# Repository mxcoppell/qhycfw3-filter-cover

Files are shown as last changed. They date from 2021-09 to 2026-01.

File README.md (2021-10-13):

# QHYCFW3 Filter Mask 3D Models

QHYCFW3S-US 7x31mm with Separators and Sunkened Screw Caps

All, the OpenSCAD script is designed/implemented for generating 3D printable models for QHYCFW3 filter wheel filter masks to make installing unmounted filters much easier. User could change the following parameter (please check with official QHYCCD CFW3 filter wheel drawings: https://www.qhyccd.com/qhycfw3/). The filter covers make filter installation to QHYCFW3 very easy - It helps to center the filters, avoid light leaks and secures the installation. It's a much better solution than the factory M.2 screws + M.2 washers. 

Please note, this design is for unmounted filters with thickness of 3mm. - For example, Chroma/Astrodon unmounted 31mm filters, unmounted 50mm round filters and Antlia unmounted 50mm round filters. If the filter thickness is 2mm or below, this solution is not feasible.

I printed mine at a local library, the cost is 30 cents in this highly-inflated world.

# Supported CFW3 Models

Currently, the following CFW3 filter wheels are supported. The square filter version is not available in current version.

- _QHYCFW3-S-SR 7x31mm_
- _QHYCFW3-S-SR 6x36mm_
- _QHYCFW3-S-US 7x31mm_
- _QHYCFW3-S-US 6x36mm_
- _QHYCFW3-M-SR 8x31mm_
- _QHYCFW3-M-SR 7x36mm_
- _QHYCFW3-M-SR 5x50mm_
- _QHYCFW3-M-US 8x31mm_
- _QHYCFW3-M-US 7x36mm_
- _QHYCFW3-M-US 5x50mm_
- _QHYCFW3-L    7x50mm_
- _QHYCFW3-XL   9x50mm_

# Filter Cover Styles

There are 4 styles with combinations of separators and sunkened screw caps. With separator, the user could easily snap the printout into individual filter covers. The sunkened screw caps requires better 3D printers. The printer I use from the local library can't really handle it well. So I just use the version without sunkened screw caps. 

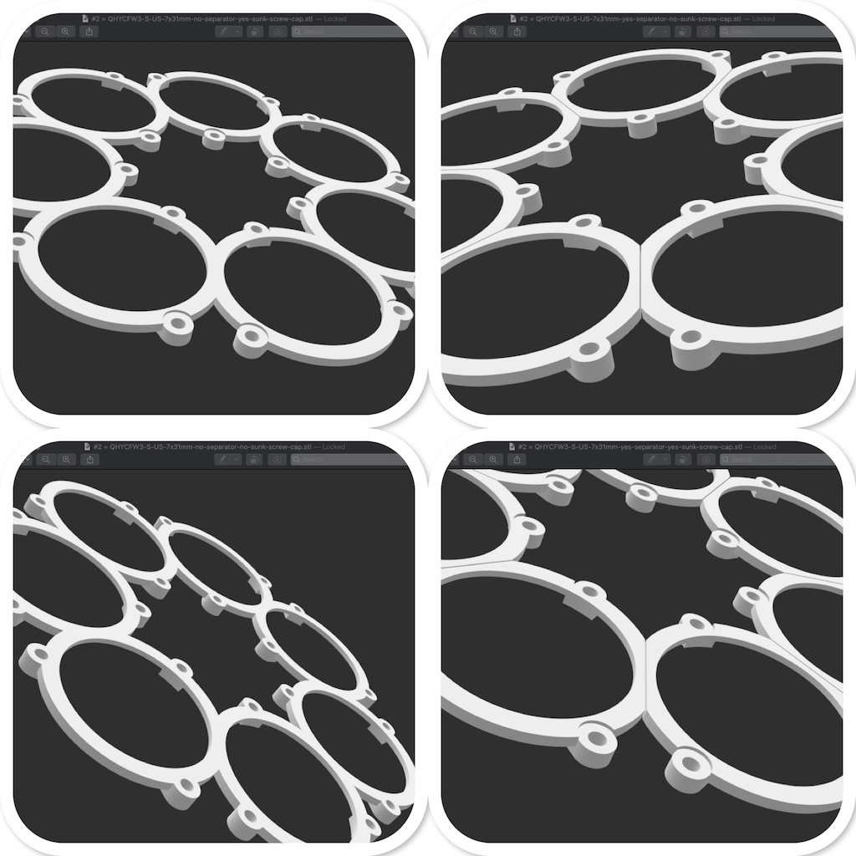
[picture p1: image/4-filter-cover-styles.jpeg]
4 Mask Cover Styles


# Pre-rendered STL Download

Pre-rendered STL files could be downloaded from the following table:
```
  S - Separators
SSC - Sunkened Screw Caps
```

| Filter Model  | No S / No SSC | No S / Yes SSC | Yes S / No SSC | Yes S / Yes SSC |
| --- | --- | --- | --- | --- |
| QHYCFW3-S-SR 7x31mm  | [download](https://github.com/mxcoppell/qhycfw3-filter-cover/blob/main/stl/%230%20%3D%20QHYCFW3-S-SR-7x31mm-no-separator-no-sunk-screw-cap.stl)  | [download](https://github.com/mxcoppell/qhycfw3-filter-cover/blob/main/stl/%230%20%3D%20QHYCFW3-S-SR-7x31mm-no-separator-yes-sunk-screw-cap.stl)  | [download](https://github.com/mxcoppell/qhycfw3-filter-cover/blob/main/stl/%230%20%3D%20QHYCFW3-S-SR-7x31mm-yes-separator-no-sunk-screw-cap.stl)  | [download](https://github.com/mxcoppell/qhycfw3-filter-cover/blob/main/stl/%230%20%3D%20QHYCFW3-S-SR-7x31mm-yes-separator-yes-sunk-screw-cap.stl)  |
| QHYCFW3-S-SR 6x36mm  | [download](https://github.com/mxcoppell/qhycfw3-filter-cover/blob/main/stl/%231%20-%20QHYCFW3-S-SR-6x36mm-no-separator-no-sunk-screw-cap.stl)  | [download](https://github.com/mxcoppell/qhycfw3-filter-cover/blob/main/stl/%231%20-%20QHYCFW3-S-SR-6x36mm-no-separator-yes-sunk-screw-cap.stl)  | [download](https://github.com/mxcoppell/qhycfw3-filter-cover/blob/main/stl/%231%20-%20QHYCFW3-S-SR-6x36mm-yes-separator-no-sunk-screw-cap.stl)  | [download](https://github.com/mxcoppell/qhycfw3-filter-cover/blob/main/stl/%231%20-%20QHYCFW3-S-SR-6x36mm-yes-separator-yes-sunk-screw-cap.stl)  |
| QHYCFW3-S-US 7x31mm  | [download](https://github.com/mxcoppell/qhycfw3-filter-cover/blob/main/stl/%232%20%3D%20QHYCFW3-S-US-7x31mm-no-separator-no-sunk-screw-cap.stl)  | [download](https://github.com/mxcoppell/qhycfw3-filter-cover/blob/main/stl/%232%20%3D%20QHYCFW3-S-US-7x31mm-no-separator-yes-sunk-screw-cap.stl)  | [download](https://github.com/mxcoppell/qhycfw3-filter-cover/blob/main/stl/%232%20%3D%20QHYCFW3-S-US-7x31mm-yes-separator-no-sunk-screw-cap.stl)  | [download](https://github.com/mxcoppell/qhycfw3-filter-cover/blob/main/stl/%232%20%3D%20QHYCFW3-S-US-7x31mm-yes-separator-yes-sunk-screw-cap.stl)  |
| QHYCFW3-S-US 6x36mm  | [download](https://github.com/mxcoppell/qhycfw3-filter-cover/blob/main/stl/%233%20-%20QHYCFW3-S-US-6x36mm-no-separator-no-sunk-screw-cap.stl)  | [download](https://github.com/mxcoppell/qhycfw3-filter-cover/blob/main/stl/%233%20-%20QHYCFW3-S-US-6x36mm-no-separator-yes-sunk-screw-cap.stl)  | [download](https://github.com/mxcoppell/qhycfw3-filter-cover/blob/main/stl/%233%20-%20QHYCFW3-S-US-6x36mm-yes-separator-no-sunk-screw-cap.stl)  | [download](https://github.com/mxcoppell/qhycfw3-filter-cover/blob/main/stl/%233%20-%20QHYCFW3-S-US-6x36mm-yes-separator-yes-sunk-screw-cap.stl)  |
| QHYCFW3-M-SR 8x31mm  | [download](https://github.com/mxcoppell/qhycfw3-filter-cover/blob/main/stl/%234%20-%20QHYCFW3-M-SR-8x31mm-no-separator-no-sunk-screw-cap.stl)  | [download](https://github.com/mxcoppell/qhycfw3-filter-cover/blob/main/stl/%234%20-%20QHYCFW3-M-SR-8x31mm-no-separator-yes-sunk-screw-cap.stl)  | [download](https://github.com/mxcoppell/qhycfw3-filter-cover/blob/main/stl/%234%20-%20QHYCFW3-M-SR-8x31mm-yes-separator-no-sunk-screw-cap.stl)  | [download](https://github.com/mxcoppell/qhycfw3-filter-cover/blob/main/stl/%234%20-%20QHYCFW3-M-SR-8x31mm-yes-separator-yes-sunk-screw-cap.stl)  |
| QHYCFW3-M-SR 7x36mm  | [download](https://github.com/mxcoppell/qhycfw3-filter-cover/blob/main/stl/%235%20-%20QHYCFW3-M-SR-7x36mm-no-separator-no-sunk-screw-cap.stl)  | [download](https://github.com/mxcoppell/qhycfw3-filter-cover/blob/main/stl/%235%20-%20QHYCFW3-M-SR-7x36mm-no-separator-yes-sunk-screw-cap.stl)  | [download](https://github.com/mxcoppell/qhycfw3-filter-cover/blob/main/stl/%235%20-%20QHYCFW3-M-SR-7x36mm-yes-separator-no-sunk-screw-cap.stl)  | [download](https://github.com/mxcoppell/qhycfw3-filter-cover/blob/main/stl/%235%20-%20QHYCFW3-M-SR-7x36mm-yes-separator-yes-sunk-screw-cap.stl)  |
| QHYCFW3-M-SR 5x50mm  | [download](https://github.com/mxcoppell/qhycfw3-filter-cover/blob/main/stl/%236%20-%20QHYCFW3-M-SR-5x50mm-no-separator-no-sunk-screw-cap.stl)  | [download](https://github.com/mxcoppell/qhycfw3-filter-cover/blob/main/stl/%236%20-%20QHYCFW3-M-SR-5x50mm-no-separator-yes-sunk-screw-cap.stl)  | [download](https://github.com/mxcoppell/qhycfw3-filter-cover/blob/main/stl/%236%20-%20QHYCFW3-M-SR-5x50mm-yes-separator-no-sunk-screw-cap.stl)  | [download](https://github.com/mxcoppell/qhycfw3-filter-cover/blob/main/stl/%236%20-%20QHYCFW3-M-SR-5x50mm-yes-separator-yes-sunk-screw-cap.stl)  |
| QHYCFW3-M-US 8x31mm  | [download](https://github.com/mxcoppell/qhycfw3-filter-cover/blob/main/stl/%237%20-%20QHYCFW3-M-US-8x31mm-no-separator-no-sunk-screw-cap.stl)  | [download](https://github.com/mxcoppell/qhycfw3-filter-cover/blob/main/stl/%237%20-%20QHYCFW3-M-US-8x31mm-no-separator-yes-sunk-screw-cap.stl)  | [download](https://github.com/mxcoppell/qhycfw3-filter-cover/blob/main/stl/%237%20-%20QHYCFW3-M-US-8x31mm-yes-separator-no-sunk-screw-cap.stl)  | [download](https://github.com/mxcoppell/qhycfw3-filter-cover/blob/main/stl/%237%20-%20QHYCFW3-M-US-8x31mm-yes-separator-yes-sunk-screw-cap.stl)  |
| QHYCFW3-M-US 7x36mm  | [download](https://github.com/mxcoppell/qhycfw3-filter-cover/blob/main/stl/%238%20-%20QHYCFW3-M-US-7x36mm-no-separator-no-sunk-screw-cap.stl)  | [download](https://github.com/mxcoppell/qhycfw3-filter-cover/blob/main/stl/%238%20-%20QHYCFW3-M-US-7x36mm-no-separator-yes-sunk-screw-cap.stl)  | [download](https://github.com/mxcoppell/qhycfw3-filter-cover/blob/main/stl/%238%20-%20QHYCFW3-M-US-7x36mm-yes-separator-no-sunk-screw-cap.stl)  | [download](https://github.com/mxcoppell/qhycfw3-filter-cover/blob/main/stl/%238%20-%20QHYCFW3-M-US-7x36mm-yes-separator-yes-sunk-screw-cap.stl)  |
| QHYCFW3-M-US 5x50mm  | [download](https://github.com/mxcoppell/qhycfw3-filter-cover/blob/main/stl/%239%20-%20QHYCFW3-M-US-5x50mm-no-separator-no-sunk-screw-cap.stl)  | [download](https://github.com/mxcoppell/qhycfw3-filter-cover/blob/main/stl/%239%20-%20QHYCFW3-M-US-5x50mm-no-separator-yes-sunk-screw-cap.stl)  | [download](https://github.com/mxcoppell/qhycfw3-filter-cover/blob/main/stl/%239%20-%20QHYCFW3-M-US-5x50mm-yes-separator-no-sunk-screw-cap.stl)  | [download](https://github.com/mxcoppell/qhycfw3-filter-cover/blob/main/stl/%239%20-%20QHYCFW3-M-US-5x50mm-yes-separator-yes-sunk-screw-cap.stl)  |
| QHYCFW3-L 7x50mm  | [download](https://github.com/mxcoppell/qhycfw3-filter-cover/blob/main/stl/%2310%20-%20QHYCFW3-L-7x50mm-no-separator-no-sunk-screw-cap.stl)  | [download](https://github.com/mxcoppell/qhycfw3-filter-cover/blob/main/stl/%2310%20-%20QHYCFW3-L-7x50mm-no-separator-yes-sunk-screw-cap.stl)  | [download](https://github.com/mxcoppell/qhycfw3-filter-cover/blob/main/stl/%2310%20-%20QHYCFW3-L-7x50mm-yes-separator-no-sunk-screw-cap.stl)  | [download](https://github.com/mxcoppell/qhycfw3-filter-cover/blob/main/stl/%2310%20-%20QHYCFW3-L-7x50mm-yes-separator-yes-sunk-screw-cap.stl)  |
| QHYCFW3-XL 9x50mm  | [download](https://github.com/mxcoppell/qhycfw3-filter-cover/blob/main/stl/%2311%20-%20QHYCFW3-XL-9x50mm-no-separator-no-sunk-screw-cap.stl)  | [download](https://github.com/mxcoppell/qhycfw3-filter-cover/blob/main/stl/%2311%20-%20QHYCFW3-XL-9x50mm-no-separator-yes-sunk-screw-cap.stl)  | [download](https://github.com/mxcoppell/qhycfw3-filter-cover/blob/main/stl/%2311%20-%20QHYCFW3-XL-9x50mm-yes-separator-no-sunk-screw-cap.stl)  | [download](https://github.com/mxcoppell/qhycfw3-filter-cover/blob/main/stl/%2311%20-%20QHYCFW3-XL-9x50mm-yes-separator-yes-sunk-screw-cap.stl)  |

# Customization

You could also download the OpenSCAD code ([qhycfw3-filter-cover.scad](https://github.com/mxcoppell/qhycfw3-filter-cover/blob/main/openscad/qhycfw3-filter-cover.scad))to do your own customization. 

The following parameters could be adjusted. (Of course you could change other part of the code to do bug fixes or design modifications.)

```
//
//  User customizable data
//
cfw_model                   = 2;        //  !!! Please set your CFW model here !!!
                                        //
                                        //   0 - QHYCFW3-S-SR 7x31mm
                                        //   1 - QHYCFW3-S-SR 6x36mm
                                        //   2 - QHYCFW3-S-US 7x31mm
                                        //   3 - QHYCFW3-S-US 6x36mm
                                        //   4 - QHYCFW3-M-SR 8x31mm
                                        //   5 - QHYCFW3-M-SR 7x36mm
                                        //   6 - QHYCFW3-M-SR 5x50mm
                                        //   7 - QHYCFW3-M-US 8x31mm
                                        //   8 - QHYCFW3-M-US 7x36mm
                                        //   9 - QHYCFW3-M-US 5x50mm
                                        //  10 - QHYCFW3-L    7x50mm
                                        //  11 - QHYCFW3-XL   9x50mm

use_filter_slot_separators  = false;    //  Pre-cut into individual filter covers
                                        //      true - cut | false - don't cut

use_screw_cap_sinks         = false;    //  Use sinks for screw caps, 
                                        //      true - use | false - don't use
                                        
cover_slot_shrink_diameter  = 0.45;     //  Diameter shink size for cover slot from QHY slot diameter
```

# Printing

It is suggested to use nozzle size <= 0.4, layer 0.1mm when printing the models. When printing, please make sure the following side is facing up (against the the printer bed). I am pretty confident any regular 3D printer could handle this job. Either ABS or PETG should be fine along with other fancier filaments. As far as it's flexible and harmless to your precious filter glasses. 

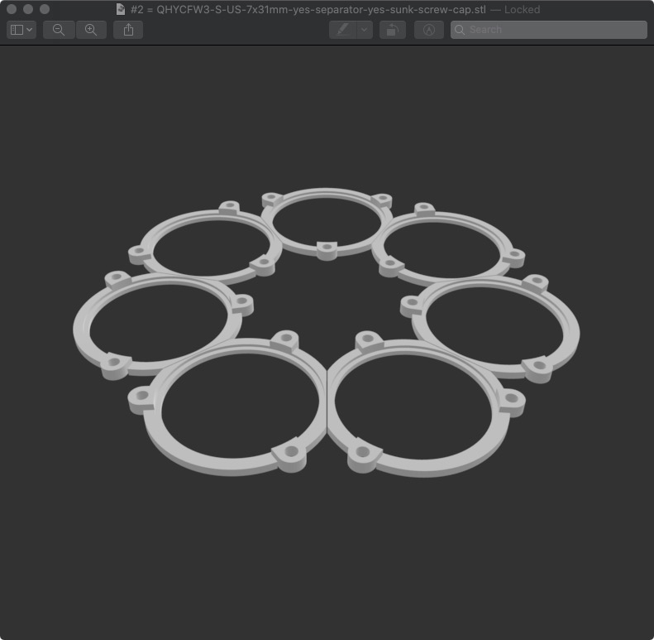
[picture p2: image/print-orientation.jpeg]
Side to face up during printing


# License

GPL - https://www.gnu.org/licenses/gpl-3.0.en.html

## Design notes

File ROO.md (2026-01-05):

# QHYCFW3 Filter Mask Project

> [!IMPORTANT]
> **Agent Instructions:** All agents MUST read this [`ROO.md`](ROO.md) file first before starting any work on the project.

This project provides an OpenSCAD script and pre-rendered STL files for creating 3D-printable filter masks for **QHYCFW3 filter wheels**.

## 1. Purpose and Target Hardware

The goal of this project is to simplify the installation of unmounted filters, improve centering, prevent light leaks, and secure filters more effectively than factory M.2 screws and washers.

- **Target Hardware:** Supports QHYCFW3 models S-SR, S-US, M-SR, M-US, L, and XL (round filters only; square filters are not supported).
- **Filter Compatibility:** Optimized for unmounted filters with a **3mm thickness** (e.g., Chroma, Astrodon, Antlia). It is not suitable for filters 2mm thick or thinner.

## 2. OpenSCAD Model Structure

The model is parametric and organized into functional modules within [`openscad/qhycfw3-filter-cover.scad`](openscad/qhycfw3-filter-cover.scad).

### Key Parameters

- `cfw_model`: Selects the specific CFW model (0–11) from a predefined dataset.
- `use_filter_slot_separators`: Boolean to include thin cuts for snapping the print into individual covers.
- `use_screw_cap_sinks`: Boolean to enable recessed screw head slots (requires high-precision printing).
- `cover_slot_shrink_diameter`: Adjusts the fit tolerance (default `0.45mm`).

### Core Modules

- `single_filter_slot()`: The primary building block, combining the filter base, screw extensions, and holes.
- `three_screw_*`: Helper modules that distribute screw features (extensions, holes, sinks) in a 120-degree pattern.
- `filter_separators()`: Generates radial cutouts to separate the masks.
- `filter_slots()` / `copy_filter_slot()`: Handles the circular arrangement of multiple masks based on the selected CFW model's geometry.

## 3. Development and Contribution Guidelines

- **Customization:** Users are encouraged to modify the OpenSCAD script for bug fixes or design improvements.
- **Printing Recommendations:**
  - **Nozzle size:** <= 0.4mm.
  - **Layer height:** 0.1mm.
  - **Material:** ABS or PETG (must be flexible and safe for glass).
  - **Orientation:** Specific "face up" orientation is required for successful printing (see [`image/print-orientation.jpeg`](image/print-orientation.jpeg)).

## 4. Environment Information

- **GitHub CLI:** The GitHub CLI (`gh`) is authenticated and ready for use in interactions with GitHub projects.

## 5. License

This project is distributed under the **GPL-3.0 License**.

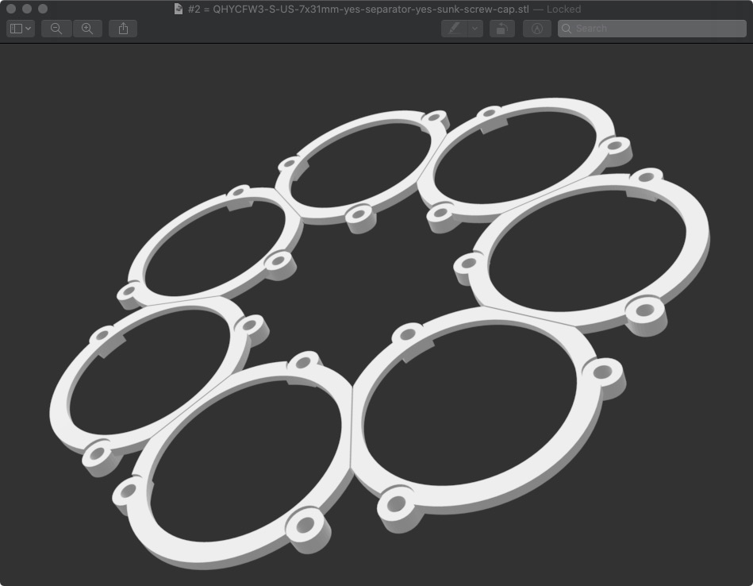
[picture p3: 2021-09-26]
image/overview.jpeg

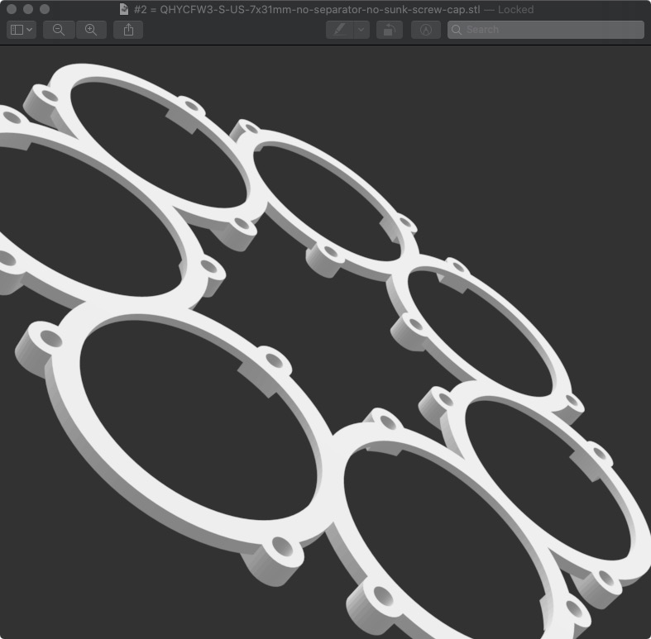
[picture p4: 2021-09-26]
image/no-separator-no-sunken.jpeg

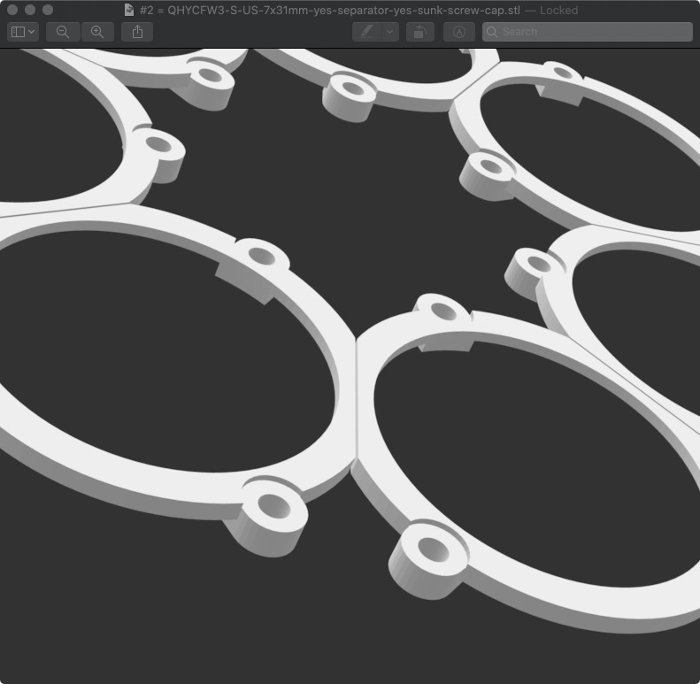
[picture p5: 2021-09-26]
image/yes-separator-yes-sunken.jpeg

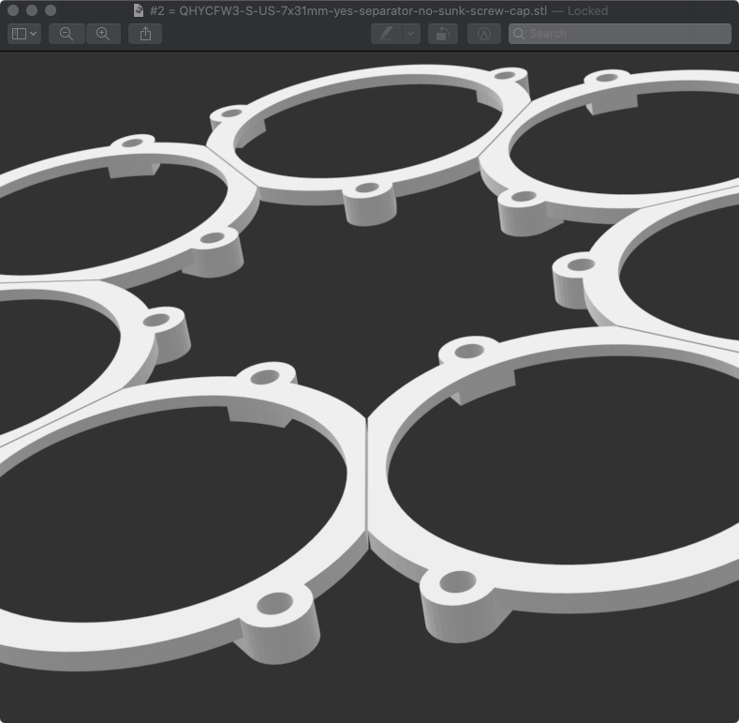
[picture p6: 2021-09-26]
image/yes-separator-no-sunken.jpeg

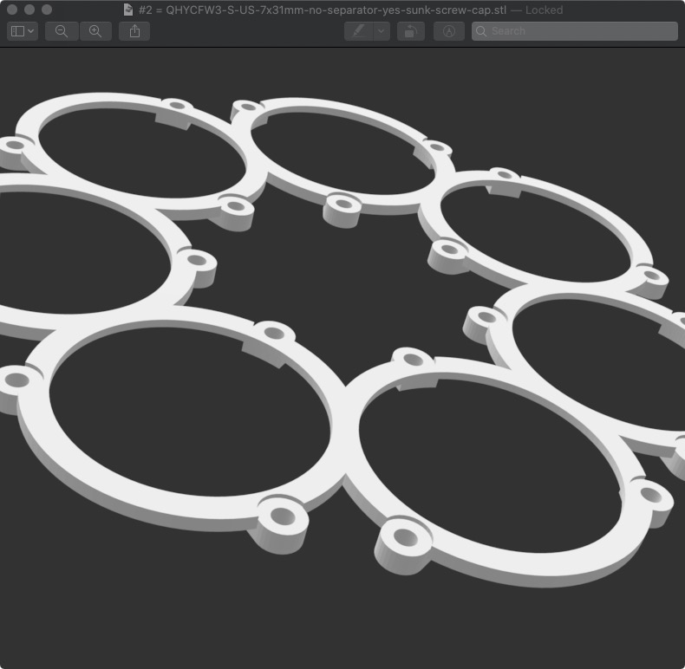
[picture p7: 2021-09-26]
image/no-separator-yes-sunken.jpeg

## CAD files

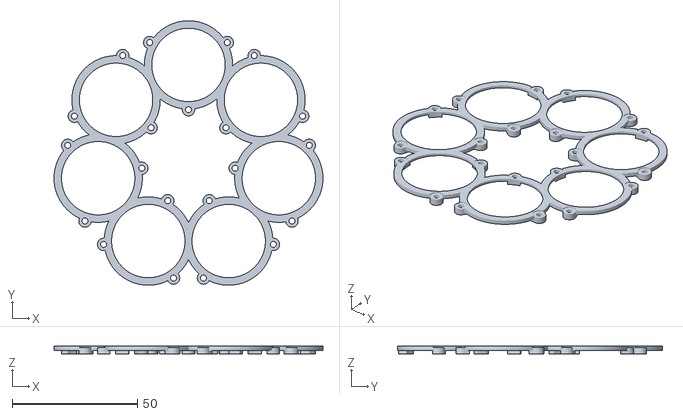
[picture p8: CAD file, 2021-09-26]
stl/#0 = QHYCFW3-S-SR-7x31mm-no-separator-yes-sunk-screw-cap.stl
107.4 x 105.6 x 3.00

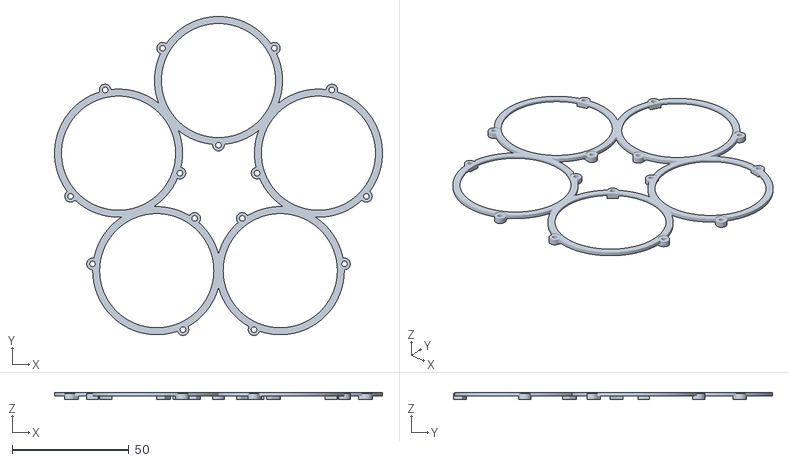
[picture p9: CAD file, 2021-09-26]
stl/#9 - QHYCFW3-M-US-5x50mm-no-separator-yes-sunk-screw-cap.stl
140.4 x 136.6 x 3.00

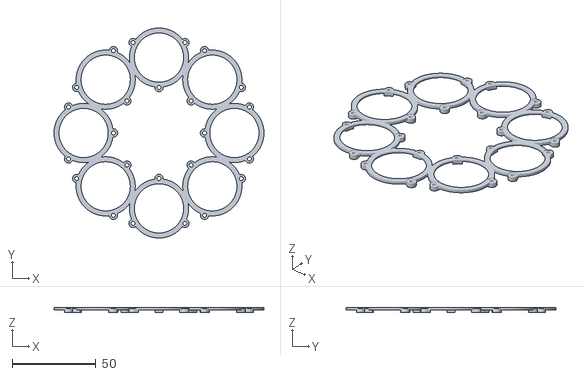
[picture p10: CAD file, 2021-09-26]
stl/#4 - QHYCFW3-M-SR-8x31mm-no-separator-yes-sunk-screw-cap.stl
125.3 x 125.3 x 3.00

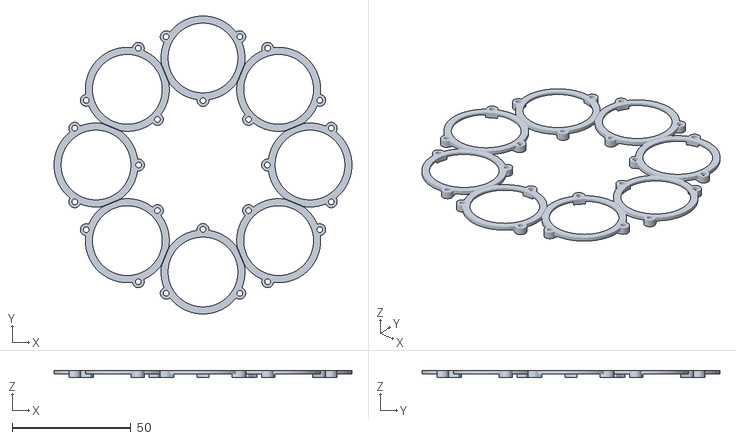
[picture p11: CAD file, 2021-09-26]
stl/#7 - QHYCFW3-M-US-8x31mm-yes-separator-no-sunk-screw-cap.stl
125.3 x 125.3 x 3.00

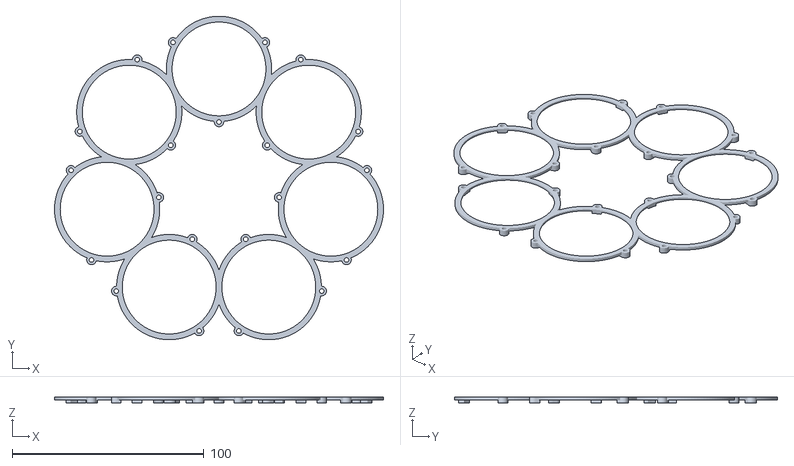
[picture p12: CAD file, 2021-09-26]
stl/#10 - QHYCFW3-L-7x50mm-no-separator-no-sunk-screw-cap.stl
171.4 x 168.5 x 3.00

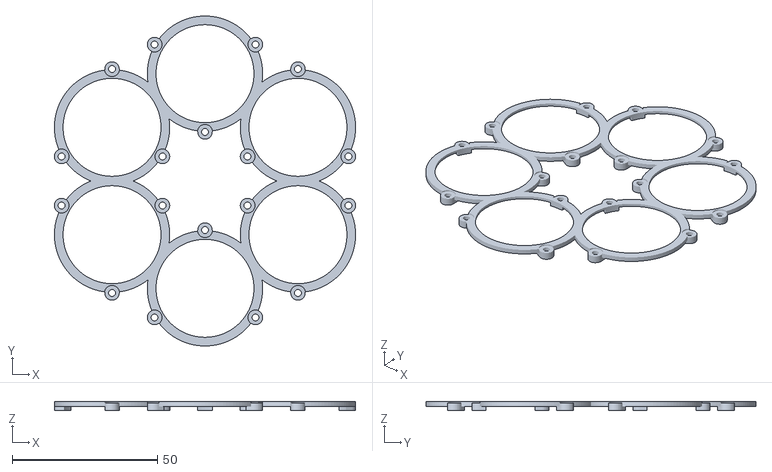
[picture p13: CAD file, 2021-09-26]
stl/#3 - QHYCFW3-S-US-6x36mm-no-separator-yes-sunk-screw-cap.stl
103.9 x 113.8 x 3.00

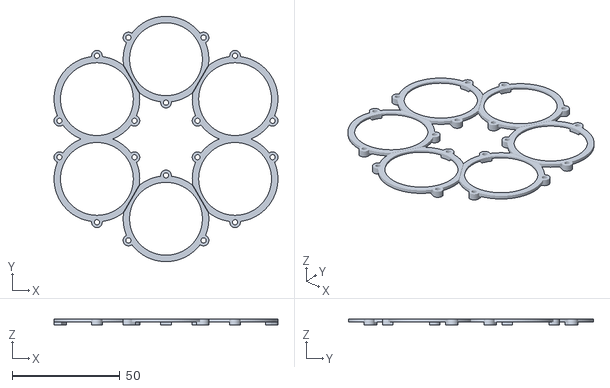
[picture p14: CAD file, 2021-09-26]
stl/#3 - QHYCFW3-S-US-6x36mm-yes-separator-no-sunk-screw-cap.stl
103.9 x 113.8 x 3.00

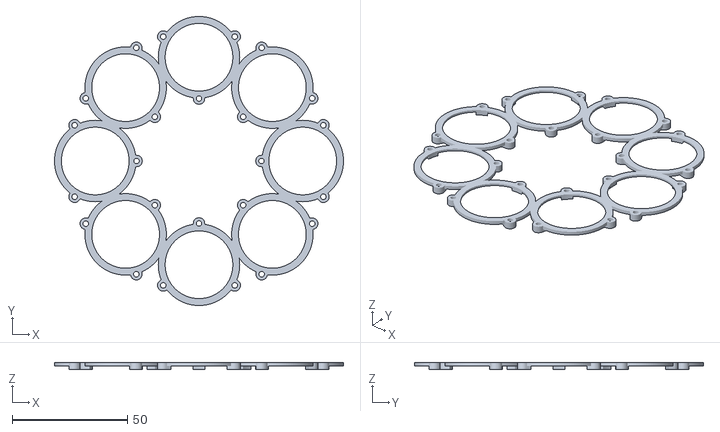
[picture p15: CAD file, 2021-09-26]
stl/#7 - QHYCFW3-M-US-8x31mm-no-separator-no-sunk-screw-cap.stl
125.3 x 125.3 x 3.00

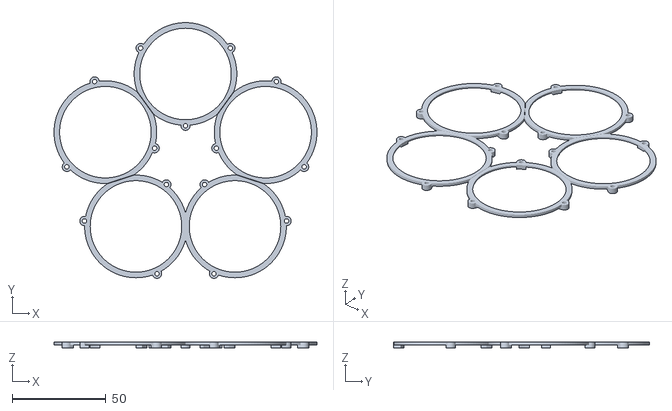
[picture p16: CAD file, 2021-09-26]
stl/#9 - QHYCFW3-M-US-5x50mm-yes-separator-no-sunk-screw-cap.stl
140.4 x 136.6 x 3.00

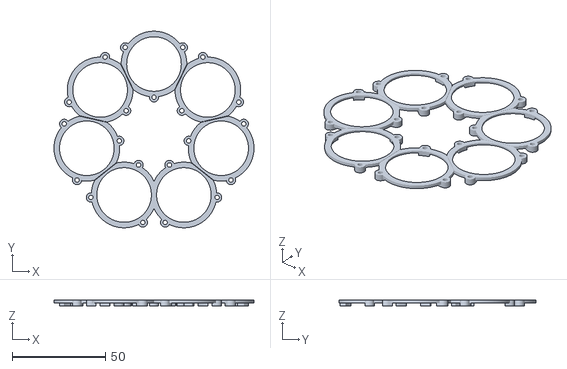
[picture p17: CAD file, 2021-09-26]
stl/#2 = QHYCFW3-S-US-7x31mm-yes-separator-no-sunk-screw-cap.stl
107.4 x 105.6 x 3.00

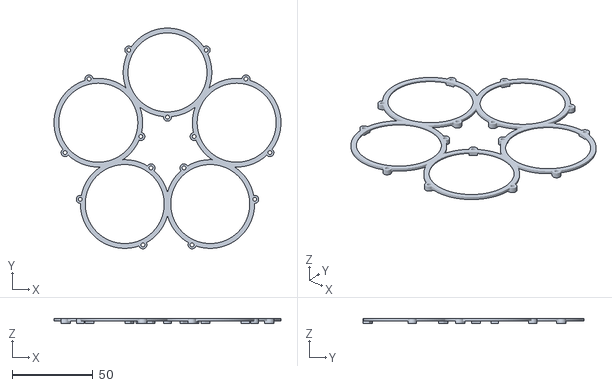
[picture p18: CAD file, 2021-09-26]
stl/#9 - QHYCFW3-M-US-5x50mm-no-separator-no-sunk-screw-cap.stl
140.4 x 136.6 x 3.00

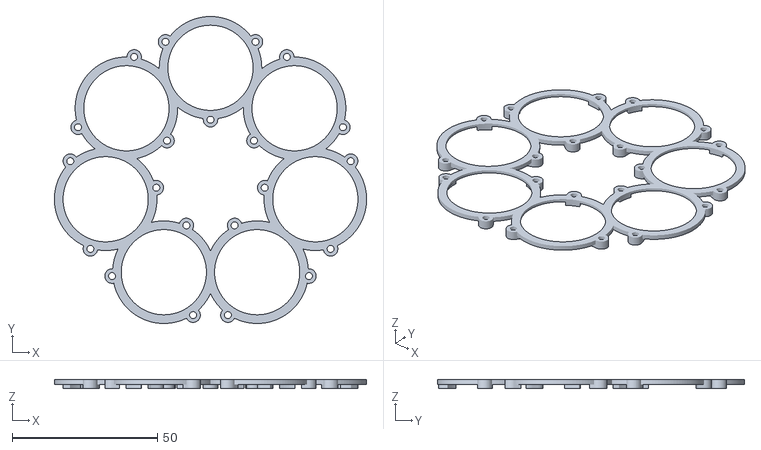
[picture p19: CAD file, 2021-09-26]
stl/#0 = QHYCFW3-S-SR-7x31mm-no-separator-no-sunk-screw-cap.stl
107.4 x 105.6 x 3.00

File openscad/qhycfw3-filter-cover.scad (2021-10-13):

//
//  User customizable data
//
cfw_model                   = 2;        //  !!! Please set your CFW model here !!!
                                        //
                                        //   0 - QHYCFW3-S-SR 7x31mm
                                        //   1 - QHYCFW3-S-SR 6x36mm
                                        //   2 - QHYCFW3-S-US 7x31mm
                                        //   3 - QHYCFW3-S-US 6x36mm
                                        //   4 - QHYCFW3-M-SR 8x31mm
                                        //   5 - QHYCFW3-M-SR 7x36mm
                                        //   6 - QHYCFW3-M-SR 5x50mm
                                        //   7 - QHYCFW3-M-US 8x31mm
                                        //   8 - QHYCFW3-M-US 7x36mm
                                        //   9 - QHYCFW3-M-US 5x50mm
                                        //  10 - QHYCFW3-L    7x50mm
                                        //  11 - QHYCFW3-XL   9x50mm


use_filter_slot_separators  =  true;    //  Pre-cut into individual filter covers
                                        //      true - cut | false - don't cut

use_screw_cap_sinks         = false;    //  Use sinks for screw caps, 
                                        //      true - use | false - don't use
                                        
cover_slot_shrink_diameter  = 0.45;     //  Diameter shink size for cover slot from QHY slot diameter


//
//  QHY Filter Wheel Dataset
//
cfw_dataset = 
[   //  number of filters, QHY filter slot diameter, CFW center to filter center distance
    [ 7, 31.75, 37.00 ],
    [ 6, 36.20, 37.00 ],
    [ 7, 31.75, 37.00 ],
    [ 6, 36.20, 37.00 ],
    [ 8, 31.80, 45.00 ],
    [ 7, 36.20, 45.00 ],
    [ 5, 51.30, 45.00 ],
    [ 8, 31.80, 45.00 ],
    [ 7, 36.20, 45.00 ],
    [ 5, 51.30, 45.00 ],
    [ 7, 51.30, /*** There is no data from QHY diagram, this is calculated value ***/59.78 ],    
    [ 9, 51.30, 80.00 ]
];
    
number_of_filters          = cfw_dataset[cfw_model][0];
cfw_filter_slot_diameter   = cfw_dataset[cfw_model][1];
cfw_center_to_slot_center  = cfw_dataset[cfw_model][2];

//  -----------------------------------------------------

// QHY design data
qhy_f_radius = cfw_filter_slot_diameter / 2;
qhy_f_screw_pad_radius = 5 / 2;
qhy_f_screw_sink = 1.5;
qhy_f_screw_center_radius = qhy_f_radius + 2;
qhy_f_screw_radius = 2 / 2 + 0.2; // M2 screw hole
qhy_f_rise_thickness = 1;

// individual filter mask
f_radius = qhy_f_radius - cover_slot_shrink_diameter / 2;
f_slot_cover_size = 0.5;
f_slot_wall_thickness = 1;

f_slot_base_radius = f_radius + f_slot_wall_thickness;
f_slot_window_radius = f_radius - f_slot_cover_size;

// filter coverage depth from top
f_slot_cover_depth = 0.8;
f_slot_window_thickness = 0.4;
f_slot_base_thickness = f_slot_cover_depth + f_slot_window_thickness;

// common variables
global_fn = 64;
extension_thickness = qhy_f_screw_sink + qhy_f_rise_thickness + f_slot_window_thickness;
rise_against_plate = (qhy_f_rise_thickness + f_slot_window_thickness) - (f_slot_window_thickness + f_slot_cover_depth);

module screw_extension()
{
    translate([0, 0, qhy_f_rise_thickness+f_slot_window_thickness-extension_thickness/2]) {
        difference() {
            union() {
                translate([0, qhy_f_screw_pad_radius-2.4/2, 0])
                    cube([qhy_f_screw_pad_radius*2, qhy_f_screw_pad_radius*2-2.4, extension_thickness], center=true);
                cylinder(h=extension_thickness,
                    r=qhy_f_screw_pad_radius, center=true, $fn=global_fn);
            }       
            cylinder(h=extension_thickness,
                r=qhy_f_screw_radius, center=true, $fn=global_fn);

        }
    }
}

module screw_cap_sink()
{
    translate([0, 0, qhy_f_rise_thickness+f_slot_window_thickness-0.5/2]) {
        cylinder(h=0.5, r=qhy_f_screw_pad_radius+0.1, center=true, $fn=global_fn);
    }
}


module screw_hole()
{
    translate([0, 0, qhy_f_rise_thickness+f_slot_window_thickness-extension_thickness/2]) {
        cylinder(h=extension_thickness, r=qhy_f_screw_radius, center=true, $fn=global_fn);
    }
}

module three_screw_extensions()
{
//    union() {
        for (i = [0, 1, 2] ) {
            translate([sin(i * 120 - 60) * qhy_f_screw_center_radius, 
                       cos(i * 120 - 60) * qhy_f_screw_center_radius, 
                       0])
                rotate([0, 0, (i * 240 - 120) % 360])
                    children();
        }
//    }
}

module three_screw_cap_sinks()
{
    if (use_screw_cap_sinks == true) {
//        union() {
            for (i = [0, 1, 2] ) {
                translate([sin(i * 120 - 60) * qhy_f_screw_center_radius, 
                           cos(i * 120 - 60) * qhy_f_screw_center_radius, 
                           0])
                    children();
            }
        }
//    }
}

module three_screw_holes()
{
//    union() {
        for (i = [0, 1, 2] ) {
            translate([sin(i * 120 - 60) * qhy_f_screw_center_radius, 
                       cos(i * 120 - 60) * qhy_f_screw_center_radius, 
                       0])
                children();
        }
//    }
}

module filter_window()
{
    translate([0, 0, f_slot_window_thickness/2 + f_slot_cover_depth + rise_against_plate])
        cylinder(h=f_slot_window_thickness, r=f_slot_window_radius, center=true, $fn=global_fn*2);
}

module filter_slot()
{
    translate([0, 0, f_slot_cover_depth/2 + rise_against_plate])
        cylinder(h=f_slot_cover_depth, r=f_radius, center=true, $fn=global_fn*2);
}

module filter_slot_through()
{
    translate([0, 0, qhy_f_rise_thickness - (extension_thickness - f_slot_window_thickness + 1)/2])
        cylinder(h=extension_thickness - f_slot_window_thickness + 1, r=f_radius, center=true, $fn=global_fn*2);
}

module filter_slot_base()
{
    difference() {
        translate([0, 0, f_slot_base_thickness/2 + rise_against_plate])
            cylinder(h=f_slot_base_thickness, r=f_slot_base_radius, center=true, $fn=global_fn*2);
        union() {
            filter_window();
            filter_slot();
        }
    }
}

module single_filter_slot()
{
    difference() { // apply screw cap sinks
        difference() { // re-apply slot and window
            difference() { // re-apply screw holes
                union() {
                    filter_slot_base();
                    three_screw_extensions()
                        screw_extension();
                }
                three_screw_holes()
                    screw_hole();
            }
            union() {
                filter_window();
                filter_slot_through();
            }
        }
        three_screw_cap_sinks()
            screw_cap_sink();
    }
 }

//  generate layout for all filters
//
module filter_slots()
{
    difference() {
        difference() {
            // assemble filters
            for (i = [0 : number_of_filters - 1] ) {
                translate([sin(i*360/number_of_filters)*cfw_center_to_slot_center, 
                           cos(i*360/number_of_filters)*cfw_center_to_slot_center, 
                           0])
                    rotate([0, 0, -i*360/number_of_filters]) 
                        single_filter_slot();
            }
            
            // cleaning up filter slots and filter windows
            for (i = [0 : number_of_filters - 1] ) {
                translate([sin(i*360/number_of_filters)*cfw_center_to_slot_center, 
                           cos(i*360/number_of_filters)*cfw_center_to_slot_center, 
                           0]) {
                    union() {
                        filter_window();
                        filter_slot_through();
                    }
                }
            }
        }
        filter_separators();
    }
}

module copy_filter_slot(){
    for (i = [0 : number_of_filters - 1] ) {
        translate([sin(i*360/number_of_filters)*cfw_center_to_slot_center, 
                   cos(i*360/number_of_filters)*cfw_center_to_slot_center, 
                   0]) 
            rotate([0, 0, -i*360/number_of_filters])
                children();
    }
}

module one_filter_slot()
{
    difference() {
        difference() {
            // assemble filters
            single_filter_slot();
            union() {
                filter_window();
                filter_slot_through();
            }
        }
        filter_separators();
    }
}

//  generate filter separators
//
module filter_separators() {
    if (use_filter_slot_separators == true) {
        for (i = [0 : number_of_filters - 1] ) {
            rotate([0, 0, 360/(number_of_filters*2) + i*360/number_of_filters])
                translate([0, 49.9, 0]) 
                    cube([0.2, 100, 30], center=true);
        }
    }
}


//  !!! give me the printable !!!
//render() filter_slots(); 
render() copy_filter_slot() //copy
    one_filter_slot();

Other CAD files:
stl/#8 - QHYCFW3-M-US-7x36mm-yes-separator-yes-sunk-screw-cap.stl
stl/#8 - QHYCFW3-M-US-7x36mm-yes-separator-no-sunk-screw-cap.stl
stl/#10 - QHYCFW3-L-7x50mm-yes-separator-no-sunk-screw-cap.stl
stl/#0 = QHYCFW3-S-SR-7x31mm-yes-separator-yes-sunk-screw-cap.stl
stl/#1 - QHYCFW3-S-SR-6x36mm-no-separator-no-sunk-screw-cap.stl
stl/#1 - QHYCFW3-S-SR-6x36mm-yes-separator-yes-sunk-screw-cap.stl
stl/#10 - QHYCFW3-L-7x50mm-no-separator-yes-sunk-screw-cap.stl
stl/#10 - QHYCFW3-L-7x50mm-yes-separator-yes-sunk-screw-cap.stl
stl/#11 - QHYCFW3-XL-9x50mm-no-separator-no-sunk-screw-cap.stl
stl/#11 - QHYCFW3-XL-9x50mm-no-separator-yes-sunk-screw-cap.stl
stl/#11 - QHYCFW3-XL-9x50mm-yes-separator-no-sunk-screw-cap.stl
stl/#11 - QHYCFW3-XL-9x50mm-yes-separator-yes-sunk-screw-cap.stl
stl/#2 = QHYCFW3-S-US-7x31mm-yes-separator-yes-sunk-screw-cap.stl
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

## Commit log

2021-09-26 Initial check-in.
    - OpenSCAD script
    - Pre-rendered STL files
    - README
    - Images
    [#0 = QHYCFW3-S-SR-7x31mm-no-separator-no-sunk-screw-cap.stl, #0 = QHYCFW3-S-SR-7x31mm-no-separator-yes-sunk-screw-cap.stl, #0 = QHYCFW3-S-SR-7x31mm-yes-separat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]
2021-10-01 Update qhycfw3-filter-cover.scad
    replace union() with children(). improve speed by 50~60%.
    [qhycfw3-filter-cover.scad]
